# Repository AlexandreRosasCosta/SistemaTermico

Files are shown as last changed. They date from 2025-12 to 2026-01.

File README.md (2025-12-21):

# 💡 Dimmer de Cargas AC com ESP32 (Monitoramento via Serial + InfluxDB)

Este projeto implementa um dimmer de controle de fase para cargas AC (resistivas) usando um ESP32. O controle de potência e a leitura de temperatura são realizados pelo firmware do ESP32, e os dados de monitoramento são enviados pela porta **Serial/USB**.

Os dados da Serial são destinados a serem consumidos por um **serviço de ponte externo** que, por sua vez, os insere no banco de dados de séries temporais **InfluxDB** para monitoramento e visualização.

---

## 🛠️ Hardware e Configuração

### 1. Componentes Principais

| Componente | Função |
| :--- | :--- |
| **Microcontrolador** | ESP32-WROOM-32D |
| **Detector de Zero-Cross** | Módulo Zero-Cross (H11AA1 - U2 no esquema) |
| **Acionador de Potência** | Optotriac (MOC3023M - U4) + Triac (BTA16-600B - Q1) |
| **Sensor de Temperatura** | Termistor NTC de 10kΩ (TH2) |

### 2. Pinagem (Conforme o Esquema)

O firmware (`.ino`) e o esquema do KiCad definem a seguinte pinagem:

| Variável | Porta (Padrão) | Função no Circuito |
| :--- | :--- | :--- |
| `PIN_ZC` | `GPIO 27` | Entrada do detector de Zero-Cross (Interrupção) |
| `PIN_MOC` | `GPIO 26` | Saída para o Optotriac (Acionamento do Triac) |
| `PIN_TEMP` | `GPIO 34` | Entrada Analógica para o Termistor NTC |

---

## 💻 Ambiente de Monitoramento (InfluxDB)

O InfluxDB é utilizado para persistir e visualizar os dados de temperatura e os estados operacionais do dimmer.

### 1. Pré-requisitos

Certifique-se de ter instalado:

* **Docker**
* **Docker Compose**
* O **Serviço de Ponte Serial** (a ser desenvolvido/implementado separadamente, que lê o Serial do ESP32 e escreve no InfluxDB).

### 2. Configuração do Ambiente (`.env`)

Configure as variáveis de ambiente necessárias para o InfluxDB no arquivo **`.env`** (localmente, fora do Git):

| Variável | Exemplo de Valor | Descrição |
| :--- | :--- | :--- |
| `INFLUX_PORT` | `8086` | Porta local para acesso ao InfluxDB (UI/API). |
| `INFLUX_TOKEN` | `token_secreto_para_api` | Token de API inicial (necessário para o seu serviço de ponte). |
| `INFLUX_BUCKET` | `dimmer_data` | Bucket (banco de dados) para os dados do dimmer. |
| `INFLUX_ORG` | `minha_org` | Organização inicial do InfluxDB. |
| (Outras) | ... | Outras variáveis de configuração do Docker. |

### 3. Inicialização do InfluxDB

Execute o container do InfluxDB usando o Docker Compose:

```bash
docker-compose up -d

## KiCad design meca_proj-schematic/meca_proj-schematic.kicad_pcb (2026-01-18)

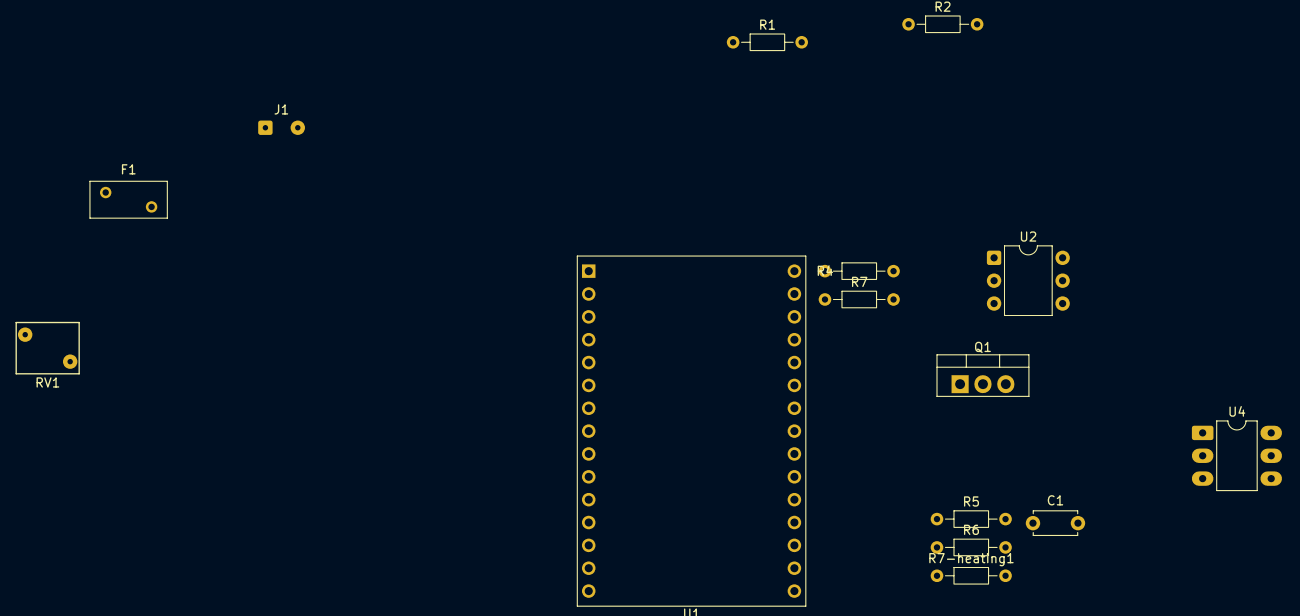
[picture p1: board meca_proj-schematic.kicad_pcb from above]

Board: 2 copper layers, 15 parts (0 on the bottom side), 12 nets, no tracks yet.

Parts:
C1: C; C_Disc_D4.7mm_W2.5mm_P5.00mm
F1: Fuse; Fuse_BelFuse_0ZRE0005FF_L8.3mm_W3.8mm
J1: Conn_01x02_Pin; SolderWire-0.1sqmm_1x02_P3.6mm_D0.4mm_OD1mm
Q1: BTA16-600B; TO-220-3_Vertical
R1, R2: R; R_Axial_DIN0204_L3.6mm_D1.6mm_P7.62mm_Horizontal
R4: 10kR; R_Axial_DIN0204_L3.6mm_D1.6mm_P7.62mm_Horizontal
R5: 500R; R_Axial_DIN0204_L3.6mm_D1.6mm_P7.62mm_Horizontal
R6: 390kR; R_Axial_DIN0204_L3.6mm_D1.6mm_P7.62mm_Horizontal
R7: 1MR; R_Axial_DIN0204_L3.6mm_D1.6mm_P7.62mm_Horizontal
R7-heating1: 780kR; R_Axial_DIN0204_L3.6mm_D1.6mm_P7.62mm_Horizontal
RV1: Varistor; RV_Disc_D7mm_W5.7mm_P5mm
U1: ESP32-S2-WROVER; ESP32-C3-DevKitM-1
U2: H11AA1; DIP-6_W7.62mm
U4: MOC3023M; DIP-6_W7.62mm_LongPads

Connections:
/N: Q1.1 (A1), RV1.2, U2.2
GND: C1.2, R7.1, U1.1 (GND), U1.26 (GND), U2.4, U4.2
unnamed: C1.1, R2.2
unnamed: F1.2, R7-heating1.2, RV1.1, U2.1
unnamed: Q1.2 (A2), R6.1, R7-heating1.1
unnamed: Q1.3 (G), U4.4
unnamed: R1.2, R2.1
unnamed: R5.1, U4.1
unnamed: R6.2, U4.6
unnamed: R7.2, U2.6
unnamed: R1.1, R4.1, U1.2 (3V3)
unnamed: R4.2, U1.21 (IO18), U2.5

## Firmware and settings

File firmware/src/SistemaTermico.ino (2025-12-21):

#include <math.h>

// ==== PINAGEM ESP32 ====
const uint8_t PIN_ZC   = 27;   // zero-cross (H11AA1)
const uint8_t PIN_MOC  = 26;   // MOC3023
const uint8_t PIN_TEMP = 34;   // NTC
#define PIN_NTC PIN_TEMP;

// ==== Controle de fase ====
volatile unsigned long semiStartUs = 0;
volatile bool newSemi = false;

// Contagem / debug zero-cross
volatile unsigned long lastZeroUs = 0;
volatile unsigned long zeroCount  = 0;

// Atraso de disparo
const unsigned long MIN_DELAY_US = 100;
const unsigned long MAX_DELAY_US = 9900;

unsigned long delay_us = MAX_DELAY_US;
float powerPercent = 0.0;

// --- Termistor ---
const double R_NOMINAL = 10000.0;
const double R_SERIE   = 13850.0;
const double BETA      = 3950.0;
const double T_NOMINAL = 298.15;
const int    AMOSTRAS  = 20;

// ===== Converte powerPercent em delay_us =====
void updateDelayFromPower()
{
  if (powerPercent < 0.0f)   powerPercent = 0.0f;
  if (powerPercent > 100.0f) powerPercent = 100.0f;

  if (powerPercent == 0.0f) {
    delay_us = 0; // não dispara o trigger
    return;
  }
  float u = powerPercent / 100.0f;
  u = u * u;  // "gamma" = 2.0 (mais suave no começo)
  delay_us = MAX_DELAY_US - (unsigned long)(u * (MAX_DELAY_US - MIN_DELAY_US));
}

// ===== ISR ZERO CROSS =====
void IRAM_ATTR onZeroCross() {
  unsigned long now = micros();
  // filtro de ruído / bounces
  if (now - lastZeroUs > 8500) {
    semiStartUs = now;
    newSemi     = true;
    zeroCount++;
  }
  lastZeroUs = now;
}

void setup() {
  Serial.begin(115200);

  pinMode(PIN_ZC,  INPUT_PULLUP);
  pinMode(PIN_MOC, OUTPUT);
  digitalWrite(PIN_MOC, LOW);

  pinMode(PIN_TEMP, INPUT);
  analogReadResolution(12);     // ADC 0..4095

  attachInterrupt(digitalPinToInterrupt(PIN_ZC), onZeroCross, FALLING);

  Serial.println("=== Dimmer ESP32 + Termistor ===");
  Serial.println("Digite um valor de potência entre 0 e 100 (%) e pressione Enter.");
  updateDelayFromPower();
}

// ======================= LOOP =========================
void loop() {
  // 1) CONTROLE DE FASE / TRIGGER  --------------------
  if (newSemi) {
    newSemi = false;
    if (powerPercent > 0.0f && delay_us > 0) {
      unsigned long fireTime = semiStartUs + delay_us;
      // espera até chegar na posição
      while ((long)(micros() - fireTime) < 0) { }
      digitalWrite(PIN_MOC, HIGH);
      delayMicroseconds(100);
      digitalWrite(PIN_MOC, LOW);
    }
  }

  // 2) LEITURA DO SERIAL PRA DEFINIR POTÊNCIA --------
  if (Serial.available() > 0) {
    String input = Serial.readStringUntil('\n');
    input.trim();
    if (input.length() > 0) {
      float val = input.toFloat();
      if (val >= 0.0f && val <= 100.0f) {
        powerPercent = val;
        updateDelayFromPower();
        Serial.print("Potência ajustada para: ");
        Serial.print(powerPercent, 3);
        Serial.print("% | Delay_us: ");
        Serial.println(delay_us);
      } else {
        Serial.println("Digite um valor entre 0 e 100.");
      }
    }
  }

  // 3) LEITURA DO TERMISTOR -----------
  static unsigned long lastTempMs = 0;
  if (millis() - lastTempMs > 500) {
    lastTempMs = millis();

    long soma_adc = 0;
    for (int i = 0; i < AMOSTRAS; i++) {
      soma_adc += analogRead(PIN_TEMP);
    }
    double adc_medio = soma_adc / (double)AMOSTRAS;

    Serial.print("ADC: ");
    Serial.print(adc_medio);

    if (adc_medio < 100 || adc_medio > 4000) {
      Serial.println(" -> ERRO ADC");
    } else {
      double resistencia_ntc =
        R_SERIE * (adc_medio / (4095.0 - adc_medio));
      double temperatura_kelvin =
        1.0 / ( (1.0 / T_NOMINAL) + (log(resistencia_ntc / R_NOMINAL) / BETA) );
      double temperatura_celsius = temperatura_kelvin - 273.15;

      Serial.print(" | Temp: ");
      Serial.print(temperatura_celsius);
      Serial.println(" °C");
    }
  }

  // 4) DEBUG DO DIMMER --------------------------------
  static unsigned long lastSendMs = 0;
  if (millis() - lastSendMs > 1000) {
    lastSendMs = millis();
    Serial.print("ZC: ");
    Serial.print(zeroCount);
    Serial.print(" | Potência: ");
    Serial.print(powerPercent, 3);
    Serial.print("% | Delay_us: ");
    Serial.println(delay_us);
  }
}

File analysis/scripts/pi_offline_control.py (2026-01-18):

import numpy as np
import matplotlib.pyplot as plt

# modelo identificado
K = 3.0826
tau = 118.9

# PI
Kp = 0.3244
Ki = 0.008414

Ts = 1.0
Tsim = np.zeros(4000)
u = np.zeros(4000)
I = 0.0

SP = 80.0
Tsim[0] = 25.0

for k in range(1, len(Tsim)):
    e = SP - Tsim[k-1]
    I_candidate = I + e*Ts

    u_unsat = Kp*e + Ki*I_candidate
    u[k] = np.clip(u_unsat, 0, 100)

    if u[k] == u_unsat:
        I = I_candidate

    # modelo térmico (Euler)
    Tsim[k] = Tsim[k-1] + Ts*((K*u[k] - Tsim[k-1]) / tau)

t = np.arange(len(Tsim))*Ts

plt.figure(figsize=(9,4))
plt.plot(t, Tsim, label="Temperatura simulada")
plt.axhline(SP, linestyle="--", label="Setpoint")
plt.plot(t, u, label="Potência (%)")
plt.legend()
plt.grid()
plt.show()

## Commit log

2025-12-08 feat: implement phase-control dimmer with NTC temperature reading and serial-based power adjustment
2025-12-13 feat: Apply power curve (gamma) for smoother dimmer control
2025-12-13 Revise README for AC dimmer project with ESP32
    Updated project description and added hardware configuration details for the AC load dimmer using ESP32.
2026-01-18 feat: add KiCad schematic and PCB project for thermal system
    [meca_proj-schematic.kicad_pcb, meca_proj-schematic.kicad_sch, power-interface.kicad_sch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]
